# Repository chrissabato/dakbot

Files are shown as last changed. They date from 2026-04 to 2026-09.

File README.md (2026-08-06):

# dakbot

MicroPython firmware for the **Waveshare ESP32-S3-ETH** that reads live scoreboard data from a **Daktronics AllSport 5000** controller, or live timing data from a **Colorado System 7** swim-timing console, and serves it as JSON over Ethernet.

dakbot
dakbot

---

## How it works

dakbot supports two consoles, selected via the **Console Type** setting:

- **Daktronics AllSport 5000** — continuously broadcasts **RTD (Real Time Data)** packets over a serial port at 19200 baud. Each packet encodes a position and a text value that slots into a fixed-width string buffer. Field names and their byte positions are defined in `daksports.json` for each supported sport.
- **Colorado System 7** (swim timing) — outputs a continuous, unframed byte stream at 9600 baud driving a display matrix (module-address bytes select a channel/segment, data bytes carry 7-segment-style values). dakbot decodes this into a fixed lane-based schema (event/heat number, running clock, and place/time per lane) — there's no `daksports.json`-style variant selection for this console, since the schema doesn't vary by sport.

The ESP32 reads the selected console's serial stream over UART, updates the in-memory scoreboard state, and serves it as JSON on demand via a lightweight HTTP server. No SD card or file writes are needed — data lives in RAM and is always current.

Supported sports (Daktronics AllSport 5000): `baseball`, `basketball`, `volleyball`, `football`, `hockeylacrosse`

Supported swim console: `Colorado System 7` (fixed 6-lane schema)

---

## Hardware

- [Waveshare ESP32-S3-ETH](https://a.co/d/0aZ7pFHl)
- [MAX3232 level shifter](https://a.co/d/0iYqtyU6)
- AllSport 5000 RTD serial output → MAX3232 level shifter → GPIO16

> The AllSport 5000 outputs RS-232 voltage levels (±12 V). A level shifter such as the MAX3232 is required to convert to the 3.3 V logic the ESP32 expects. Connecting RS-232 directly will damage the board.

> **Colorado System 7:** this repo assumes the console's serial output is also RS-232 and requires the same MAX3232 level-shifting approach — but this is **unconfirmed**. There's no documented connector pinout or voltage spec for the Colorado System 7 in this repo (unlike the AllSport 5000's DB25 pinout below). Confirm the actual output voltage and connector pinout on your specific unit before wiring it to the ESP32; connecting the wrong voltage level directly will damage the board.

### Serial cable

The AllSport 5000 has a DB25 male RTD output. Wire it to a DB9 female connector for a standard MAX3232 module:

| AllSport 5000 DB25 Male | DB9 Female | Signal |
|---|---|---|
| Pin 7 | Pin 5 | GND |
| Pin 2 | Pin 3 | TX → RX |
| Pin 3 | Pin 2 | RX → TX (unused — receive only) |

### ESP Wiring

| MAX3232 | ESP32-S3-ETH |
|---|---|
| ACC | 3V3 |
| GND | GND |
| R1OUT | GPIO16 (UART RX) |
| R1IN | — |

GPIO17 is configured as UART TX but left unconnected — the AllSport link is receive-only.

### W5500 pins (fixed on-board, do not change)

| Signal | GPIO |
|---|---|
| SCLK | 13 |
| MOSI | 11 |
| MISO | 12 |
| CS | 14 |
| INT | 10 |
| RST | 9 |

---

## Installation

### Blank board setup

Requires Python 3. From inside the `dakbot` repo folder:

```bash
./setup.sh PORT
```

Replace `PORT` with your serial port:
- **Windows:** `COM3`, `COM4`, etc. — check Device Manager
- **Mac:** `/dev/cu.usbmodem*` or `/dev/cu.usbserial*`
- **Linux:** `/dev/ttyACM0` or `/dev/ttyUSB0`

The script installs `esptool`/`mpremote` if missing, downloads the latest stable MicroPython firmware for `ESP32_GENERIC_S3`, erases and flashes the board, verifies W5500 (Ethernet) support, and copies all project files. It will pause and prompt you to put the board in bootloader mode (hold **BOOT**, press and release **RESET**, release **BOOT**) and again to reset after flashing.

If W5500 verification fails, re-run with a manually downloaded `ESP32_GENERIC_S3-SPIRAM` build from [micropython.org/download/ESP32_GENERIC_S3](https://micropython.org/download/ESP32_GENERIC_S3/) by placing it in `/tmp/dakbot-firmware/` before running the script.

### Boot and verify

Press **RESET**. Connect to the REPL to see startup output:

```
Settings loaded from settings.json
Ethernet connected: ('192.168.x.x', '255.255.255.0', ...)
Sport: baseball | RTD buffer: 343 chars
HTTP server listening on port 80
Serial reader started
```

With Console Type set to Colorado System 7, the sport/RTD lines are replaced with:

```
Console: Colorado System 7
HTTP server listening on port 80
Colorado reader started
```

Open `http://<ip-shown-above>/settings` in a browser to confirm the UI is up.

---

## Configuration

User settings (sport, network, UART RX pin) are managed through the web UI at `/settings` and stored in `settings.json` on the device. Default values are defined in `settings.py`.

`config.py` contains only hardware pin constants fixed by the PCB — these should not need to change.

---

## Flashing updated code

After the initial install, copy individual changed files with `mpremote`:

```bash
mpremote connect PORT cp main.py :main.py
```

`settings.json` lives only on the device and is not overwritten by copying project files.

---

## Settings UI

Navigate to `http://<device-ip>/settings` to configure the device without reflashing.

| Setting | Notes |
|---|---|
| Console Type | Daktronics AllSport 5000 or Colorado System 7 — reboot required |
| Sport | Daktronics only; updates field mapping immediately on next reboot |
| DHCP / Static IP | Reboot required |
| HTTP Port | Reboot required |
| UART RX Pin | GPIO wired to the MAX3232 output — reboot required |
| MQTT Enable | Toggle MQTT publishing — reboot required |
| MQTT Broker | Hostname of the MQTT broker (TLS port 8883) |
| MQTT Topic | Topic to publish score data to (default: `dakbot/score`) |

Settings are persisted to `settings.json` on the device flash and survive reboots. Hardware pin constants (W5500 SPI lines, UART baud) stay in `config.py` and require reflashing to change.

---

## API

| Endpoint | Method | Description |
|---|---|---|
| `/` | GET | Live scoreboard JSON |
| `/data` | GET | Same (alias) |
| `/settings` | GET | Settings UI + device status dashboard (temp, RAM, uptime) |
| `/settings` | GET | Settings UI (HTML) |
| `/settings` | POST | Save settings to flash |
| `/reboot` | POST | Reboot device |
| `/update` | POST | OTA update from GitHub main branch |

All responses include `Access-Control-Allow-Origin: *`.

Example response (baseball):

```json
{
    "HomeTeamName": "HOME",
    "AwayTeamName": "GUEST",
    "HomeTeamScore": "9",
    "AwayTeamScore": "4",
    "Inning": "9",
    "InningText": "9TH",
    "InningDescription": "BOT of 9TH",
    "TB": "▼",
    "top": "",
    "bottom": "▼",
    "Ball": "0",
    "Strike": "0",
    "Out": "0",
    "Count": "0-0",
    "Outs": "⚪⚪⚪"
}
```

Example response (Colorado System 7):

```json
{
    "EventNumber": "12",
    "HeatNumber": "3",
    "Clock": "1:23",
    "Lane1Label": "1", "Lane1Place": "", "Lane1Time": "",
    "Lane2Label": "2", "Lane2Place": "1", "Lane2Time": "58.32",
    "Lane3Label": "3", "Lane3Place": "", "Lane3Time": "",
    "Lane4Label": "4", "Lane4Place": "", "Lane4Time": "",
    "Lane5Label": "5", "Lane5Place": "", "Lane5Time": "",
    "Lane6Label": "6", "Lane6Place": "", "Lane6Time": "",
    "console": "colorado"
}
```

---

## Files

| File | Purpose |
|---|---|
| `main.py` | Entry point — Ethernet init, async task runner |
| `daktronics.py` | Async AllSport 5000 RTD serial parser (machine.UART) |
| `colorado.py` | Async Colorado System 7 serial parser (machine.UART) |
| `webserver.py` | Minimal async HTTP server (uasyncio) |
| `mqtt_publisher.py` | Optional async MQTT publisher (TLS, port 8883) |
| `updater.py` | OTA updater — fetches project files from GitHub over HTTPS |
| `index.html` | Browser scoreboard — connects via MQTT WebSocket (WSS, port 8884); hosted at [chrissabato.github.io/dakbot](https://chrissabato.github.io/dakbot) |
| `config.py` | Hardware pin constants (PCB-fixed, do not change) |
| `settings.py` | Persistent user settings — loads/saves `settings.json` on flash |
| `daksports.json` | Field name → [position, length] mappings per sport |
| `setup.sh` | Full setup of a blank board — flash MicroPython + copy project files |
| `flash.sh` | Copy project files to an already-flashed board |

---

## MQTT / Public scoreboard

Enable MQTT in the `/settings` UI to push live scores to any MQTT broker. The browser client (`client.html`) connects to the same broker via WebSocket and displays the scoreboard in real time.

### Quick setup with HiveMQ Cloud (free tier)

1. Create a free cluster at [hivemq.com](https://www.hivemq.com/mqtt-cloud-broker/) — 10 connections, unlimited messages.
2. Create two credentials: one for the ESP32 (publish), one for the browser (subscribe-only).
3. In the Dakbot settings UI:
   - Enable MQTT
   - Broker: `xxxx.s1.eu.hivemq.cloud` (your cluster hostname)
   - Port: `8883` (TLS)
   - Fill in the ESP32 username/password
   - Topic: `dakbot/score` (or any string)
4. Install `umqtt.simple` on the device (one-time):
   ```bash
   mpremote connect PORT mip install umqtt.simple
   ```
5. Open `client.html` in any browser, enter the broker hostname, WSS port `8884`, and the browser credential.

The ESP32 publishes with `retain=True`, so late-joining browsers immediately receive the current score.

---

## 3D Printed Case

A 3MF print file for a case enclosing the ESP32-S3-ETH and MAX3232 module is included in [`resources/Dakbot Case.3mf`](https://github.com/chrissabato/dakbot/raw/main/resources/Dakbot%20Case.3mf). Open it in PrusaSlicer, Bambu Studio, or any slicer that supports the 3MF format.

---

## Credits

RTD serial parsing based on original work by [Alex Riviere](https://github.com/fimion) — [scoredata](https://github.com/chrisdeely/scoredata).

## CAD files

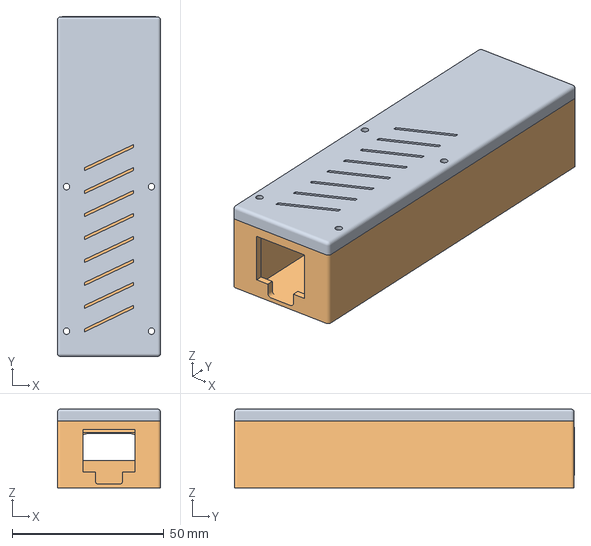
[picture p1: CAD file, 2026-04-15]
resources/Dakbot Case.3mf
34.0 x 112.1 x 26.0 mm

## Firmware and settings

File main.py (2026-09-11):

# =============================================================================
# main.py — ESP32-S3 Daktronics AllSport 5000 / Colorado System 7 → JSON web server
#
# Reads serial data from a Daktronics AllSport 5000 scoreboard controller or a
# Colorado System 7 swim-timing console (selected via the "console" setting),
# parses it into a dict, and serves the current state as JSON over Ethernet.
# A web UI at /settings allows configuration without reflashing.
#
# MicroPython build requirement:
#   The standard ESP32-S3 MicroPython binary does NOT include W5500 support.
#   You need a build compiled with: MICROPY_PY_NETWORK_WIZNET5K=5500
#   Build from source:
#     make BOARD=ESP32_GENERIC_S3 MICROPY_PY_NETWORK_WIZNET5K=5500
#   Verify: import network; print(hasattr(network, 'PHY_W5500'))  # must be True
#
# Flash the following files to the device root (/):
#   main.py, config.py, settings.py, daktronics.py, colorado.py, webserver.py,
#   daksports.json
# =============================================================================

import ujson
import uasyncio as asyncio
from machine import SPI, Pin

import config
import settings
import webserver
from daktronics import Daktronics


# =============================================================================
# Ethernet initialisation
# =============================================================================
def init_ethernet():
    """
    Bring up the W5500 using the ESP32-port network.LAN API.

    IMPORTANT: network.WIZNET5K is the RP2040/Pico API — it does not exist on
    ESP32. The correct API is network.LAN with phy_type=network.PHY_W5500.
    The INT pin is mandatory; the driver is interrupt-driven, not polling.

    For LAN8720 RMII boards (plain ESP32, not S3) swap to:
        nic = network.LAN(mdc=Pin(23), mdio=Pin(18),
                          phy_type=network.PHY_LAN8720, phy_addr=1)
    """
    import network
    import time

    spi = SPI(
        config.SPI_ID,
        baudrate=40_000_000,
        sck=Pin(config.SPI_SCK),    # GPIO13
        mosi=Pin(config.SPI_MOSI),  # GPIO11
        miso=Pin(config.SPI_MISO),  # GPIO12
    )

    nic = network.LAN(
        spi=spi,
        phy_type=network.PHY_W5500,
        phy_addr=0,                     # always 0 for SPI-based W5500
        cs=Pin(config.W5500_CS),        # GPIO14
        int=Pin(config.W5500_INT),      # GPIO10 — required by driver
        reset=Pin(config.W5500_RST),    # GPIO9
    )

    nic.active(True)

    try:
        settings.set_mac(nic.config('mac'))
    except Exception as e:
        print('WARNING: could not read Ethernet MAC:', e)

    s = settings.current
    if s.get('use_dhcp'):
        nic.ifconfig('dhcp')
        for _ in range(30):             # wait up to 15 s for DHCP lease
            if nic.isconnected():
                break
            time.sleep(0.5)
    else:
        nic.ifconfig((
            s.get('ip',      '192.168.1.100'),
            s.get('mask',    '255.255.255.0'),
            s.get('gateway', '192.168.1.1'),
            s.get('dns',     '8.8.8.8'),
        ))

    if nic.isconnected():
        print('Ethernet connected:', nic.ifconfig())
        webserver.device_ip = nic.ifconfig()[0]
    else:
        print('WARNING: Ethernet not connected — check wiring / settings')

    return nic


# =============================================================================
# Score processing
# =============================================================================

def build_score_dict(dak, sport_config):
    """Extract all fields from the RTD buffer into a flat dict."""
    data = {}
    for key in sport_config:
        data[key] = dak[key].strip()
    return data


# --- Sport-specific post-processors -----------------------------------------
# Each function receives the data dict and mutates it in place.
# Add a new entry here to support additional sports.

def _process_baseball(data):
    if 'HomeAtBat' in data:
        data['HomeAtBat'] = data['HomeAtBat'].replace('<', '>')

    ball, strike = data.get('Ball', ''), data.get('Strike', '')
    data['Count'] = '{}-{}'.format(ball, strike) if ball and strike else ''

    out_str = data.get('Out', '').strip()
    data['Outs'] = (
        '\u26ab\u26ab\u26ab' if out_str == '3' else   # ⚫⚫⚫
        '\u26ab\u26ab\u26aa' if out_str == '2' else   # ⚫⚫⚪
        '\u26ab\u26aa\u26aa' if out_str == '1' else   # ⚫⚪⚪
        '\u26aa\u26aa\u26aa' if out_str == '0' else   # ⚪⚪⚪
        ''
    )

    inning_state = data.get('InningDescription', '').lower()
    tb = (
        '\u25bc' if 'bot' in inning_state else
        '\u25b2' if 'top' in inning_state else
        ''
    )
    data['TB']     = tb
    data['top']    = '\u25b2' if tb == '\u25b2' else ''
    data['bottom'] = '\u25bc' if tb == '\u25bc' else ''

def _timeout_display(count_str):
    """2 -> '——'; blank/non-numeric -> ''."""
    try:
        n = int(count_str)
    except (ValueError, TypeError):
        return ''
    return '—' * n


def _process_football(data):
    down, togo = data.get('Down', ''), data.get('ToGo', '')
    data['DownAndDistance'] = '{} & {}'.format(down, togo) if down and togo else ''

    data['HomeTimeoutDisplay'] = _timeout_display(data.get('HomeTimeOutsLeft-Total', ''))
    data['AwayTimeoutDisplay'] = _timeout_display(data.get('AwayTimeOutsLeft-Total', ''))

    play_clock = data.get('PlayClockTime', '')
    try:
        under_10 = int(play_clock) < 10
    except (ValueError, TypeError):
        under_10 = False
    data['PlayClockTimeAlert'] = play_clock if under_10 else ''


_SPORT_PROCESSORS = {
    'baseball': _process_baseball,
    # 'basketball': _process_basketball,
    'football':   _process_football,
}


def apply_sport_processing(data, sport_name):
    processor = _SPORT_PROCESSORS.get(sport_name)
    if processor:
        processor(data)


# =============================================================================
# Async tasks
# =============================================================================
# Fields excluded from the "keep last known non-empty value" fallback below —
# these legitimately go blank as a normal state transition (not a serial
# glitch), so sticking them would make them permanently latch to their first
# non-blank value.
_STICKY_EXCLUDED = (
    'AwayAtBat', 'HomeAtBat',
    'DownAndDistance', 'HomeTimeoutDisplay', 'AwayTimeoutDisplay',
    'PlayClockTimeAlert',
)


async def serial_reader_task(dak, sport_config, sport_name, mqtt_enabled=False):
    """Read RTD packets continuously, yield between bytes for HTTP responsiveness."""
    print('Serial reader started')
    _mqtt_enabled = mqtt_enabled
    while True:
        try:
            await dak.update()
            new_data = build_score_dict(dak, sport_config)
            apply_sport_processing(new_data, sport_name)

            # Keep last known non-empty value for fields that report blank mid-packet
            for key, val in new_data.items():
                if key not in _STICKY_EXCLUDED:
                    if val == '' and key in webserver.score_data:
                        new_data[key] = webserver.score_data[key]

            new_data['sport'] = sport_name
            new_data['console'] = 'daktronics'
            webserver.score_data.update(new_data)

            # Signal MQTT publisher that fresh data is available
            if _mqtt_enabled:
                import mqtt_publisher
                mqtt_publisher.data_ready.set()

        except Exception as e:
            print('Serial reader error:', e)
            await asyncio.sleep_ms(500)


async def colorado_reader_task(cw, mqtt_enabled=False):
    """Read Colorado System 7 data continuously. update() only returns once
    a meaningful field has changed (see colorado.py)."""
    print('Colorado reader started')
    while True:
        try:
            await cw.update()
            new_data = cw.to_dict()
            new_data['console'] = 'colorado'
            webserver.score_data.update(new_data)

            if mqtt_enabled:
                import mqtt_publisher
                mqtt_publisher.data_ready.set()

        except Exception as e:
            print('Colorado reader error:', e)
            await asyncio.sleep_ms(500)


# =============================================================================
# Entry point
# =============================================================================
async def main():
    # 1. Ethernet (reads network settings from settings.current)
    init_ethernet()

    mqtt_enabled = bool(settings.current.get('mqtt_enabled'))
    console_type = settings.current.get('console', 'daktronics')

    # 2. Initialise the selected console's serial parser
    if console_type == 'colorado':
        from colorado import Colorado
        cw = Colorado(
            uart_id=config.UART_ID,
            rx_pin=settings.current['uart_rx'],
            tx_pin=settings.current.get('uart_tx', 17),
            baud=config.COLORADO_BAUD,
        )
        print('Console: Colorado System 7')

        # Seed score_data so the endpoint always returns valid JSON before first update
        webserver.score_data = cw.to_dict()
        webserver.score_data['console']     = 'colorado'
        webserver.score_data['device_name'] = settings.device_name()

        reader = colorado_reader_task(cw, mqtt_enabled)

    else:
        with open('daksports.json') as f:
            all_sports = ujson.load(f)

        sport_name   = settings.current['sport']
        sport_config = all_sports[sport_name]
        print('Sport:', sport_name, ' | RTD buffer:', sport_config['dakSize'][1], 'chars')

        dak = Daktronics(
            sport_config,
            uart_id=config.UART_ID,
            rx_pin=settings.current['uart_rx'],
            tx_pin=settings.current.get('uart_tx', 17),
            baud=config.UART_BAUD,
        )

        # Seed score_data so the endpoint always returns valid JSON before first packet
        webserver.score_data = {key: '' for key in sport_config}
        webserver.score_data['sport']       = sport_name
        webserver.score_data['console']     = 'daktronics'
        webserver.score_data['device_name'] = settings.device_name()

        reader = serial_reader_task(dak, sport_config, sport_name, mqtt_enabled)

    # 3. Run HTTP server and serial reader concurrently
    await webserver.start(port=settings.current.get('http_port', 80))

    tasks = [asyncio.create_task(reader)]

    # 4. Optionally start MQTT publisher
    if mqtt_enabled:
        import mqtt_publisher
        tasks.append(asyncio.create_task(
            mqtt_publisher.run(lambda: webserver.score_data)
        ))
        print('MQTT publisher task started')

    await asyncio.gather(*tasks)


asyncio.run(main())

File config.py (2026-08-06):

# =============================================================================
# config.py — Hardware-only constants for the Waveshare ESP32-S3-ETH
#
# These are fixed by the PCB and should not be changed.
# User-configurable settings (sport, IP, etc.) live in settings.py and are
# persisted to settings.json on the device flash.
#
# Pin assignments verified against the ESP32-S3-ETH schematic:
#   https://files.waveshare.com/wiki/ESP32-S3-ETH/ESP32-S3-ETH-Schematic.pdf
# =============================================================================

# --- UART hardware -----------------------------------------------------------
UART_ID       = 1
UART_BAUD     = 19200   # AllSport 5000 RTD fixed baud rate
COLORADO_BAUD = 9600    # Colorado System 7 fixed baud rate

# --- Ethernet (W5500 via SPI) ------------------------------------------------
# On ESP32-S3, W5500 uses network.LAN(phy_type=network.PHY_W5500, ...).
# network.WIZNET5K is the RP2040/Pico API and does not exist on ESP32.
# The INT pin is required — the driver is interrupt-driven, not polling.
SPI_ID    = 2    # SPI2 (HSPI) — SPI0/1 are reserved for internal flash
SPI_SCK   = 13   # W5500 SCLK
SPI_MOSI  = 11   # W5500 MOSI
SPI_MISO  = 12   # W5500 MISO
W5500_CS  = 14   # W5500 SCSn (chip select)
W5500_RST = 9    # W5500 RSTn (active-low reset)
W5500_INT = 10   # W5500 INTn (interrupt — required by network.LAN driver)

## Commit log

2026-04-06 Initial commit: Daktronics AllSport 5000 scoreboard reader
    Original Python/pyserial implementation (daktronics.py, scorebug.py)
    plus ESP32-S3 MicroPython port targeting the Waveshare ESP32-S3-ETH board.
    The ESP32 port reads RTD serial data over UART, parses it using the
    same positional field mapping from daksports.json, and serves live
    scoreboard JSON over Ethernet via a lightweight async HTTP server.
2026-04-06 Add README
    Covers both the Python/PC implementation and the ESP32-S3 MicroPython
    port: hardware wiring, level shifter requirement, firmware build notes,
    flashing instructions, and HTTP API reference.
2026-04-06 Restructure as ESP32-S3 MicroPython project
    Remove legacy Python/pyserial implementation. Promote esp32/ contents
    to repo root. Update README to reflect ESP32-only scope.
2026-04-06 Add web UI for settings management
    - settings.py: persistent user settings (sport, network, UART RX pin)
    loaded from settings.json on flash; falls back to defaults if missing
    - webserver.py: add GET/POST /settings (HTML form), POST /reboot;
    URL-decode helper and form parser for handling POST bodies
    - config.py: strip to hardware-only pin constants; all user config
    moved to settings.py
    - main.py: read sport, network, and UART RX from settings.current
    - .gitignore: exclude settings.json (device-specific, generated at runtime)
    - README: update configuration section and API table
    [config.py, main.py, settings.py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]
2026-04-08 Add flash.sh script for copying files to device
    Usage: ./flash.sh [port] (defaults to /dev/ttyACM0)
2026-04-08 Fix flash.sh to copy files individually
    Chained mpremote + syntax was unreliable. Copy each file in a
    separate mpremote call with error checking.
2026-04-09 Add MQTT publishing and browser scoreboard client
    - settings.py: add mqtt_enabled, broker, port, user, password, topic defaults
    - mqtt_publisher.py: async TLS MQTT publisher; publishes on change, pings every 30s, reconnects on failure
    - webserver.py: add MQTT section to settings form and POST handler
    - main.py: conditionally start MQTT task via asyncio.gather
    - client.html: browser scoreboard using MQTT.js over WSS; config panel for broker credentials
    - flash.sh: include mqtt_publisher.py in copy list
    - README: document MQTT setup with HiveMQ Cloud
    [main.py, mqtt_publisher.py, settings.py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]
2026-04-10 Add sport-specific scoreboard layouts to browser client
    Each sport now has a dedicated renderer showing only relevant fields:
    - Baseball: inning description, count/outs, H/E/LOB table
    - Basketball: game/period + clock, fouls, bonus, shot clock
    - Football: quarter + clock, down & distance, ball on, play clock
    - Volleyball: set number, sets won, serve indicator
    - Hockey/Lacrosse: period + clock, shots on goal, saves
    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
2026-04-10 Replace MQTT polling with event-driven publish
    mqtt_publisher now waits on an asyncio.Event (data_ready) instead of
    sleeping on a timer. serial_reader_task sets the event on every RTD
    packet, triggering an immediate publish. Eliminates up to 1s polling
    delay — latency is now just the broker round-trip (~200-300ms).
    [main.py, mqtt_publisher.py]
2026-04-10 Fix MicroPython API errors in mqtt_publisher
    asyncio.ticks_ms/ticks_diff/wait_for_ms don't exist in uasyncio.
    Use utime.ticks_ms/ticks_diff and asyncio.wait_for (seconds) instead.
    These crashes were preventing the HTTP server from responding.
    [mqtt_publisher.py]
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2026-04-11 Add OTA firmware update from GitHub via settings UI
    - updater.py: fetches each project file from raw.githubusercontent.com
    over HTTPS using raw sockets + TLS (no extra packages needed).
    Writes to a .tmp file then renames for safety. settings.json is never touched.
    - webserver.py: POST /update runs the updater and shows a results page
    with per-file status; includes a Reboot button to apply.
    Settings page has an 'Update from GitHub' button with a loading state.
    - flash.sh: include updater.py in initial flash
    - README: document /update endpoint and updater.py file
    [updater.py, webserver.py]
2026-04-11 Add device status dashboard to settings page
    Renders IP, sport, MCU temp, RAM, and uptime directly in the settings
    page response — no separate endpoint or JS polling needed.
    Removed /health and /status endpoints.
2026-04-11 Fix OTA update hanging — send response before downloading files
    The update handler now responds immediately with a progress page, then
    starts the download in a background asyncio task. Previously the
    synchronous HTTPS downloads blocked the event loop before the HTTP
    response could be flushed, leaving the browser spinning forever.
    [webserver.py]
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2026-04-11 Fix TypeError crash in settings page — remove double unary +
    [webserver.py]
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2026-04-14 Switch browser MQTT client to self-hosted Mosquitto broker
    Default host/port/user now points to stats.chrissabato.com via Apache
    WSS proxy on port 443. Update config panel note accordingly.
2026-04-15 Add 3D printed case file and document in README
    [Dakbot Case.3mf]
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2026-04-16 Remove index.json, ignore monitor.py, fix TB field for neutral inning state
    TB now returns empty string when InningDescription is neither top nor bottom.
    [main.py]
2026-07-30 Send Cache-Control: no-store on HTTP responses
    Prevents browsers from serving a stale cached JSON/settings response
    instead of hitting the device for fresh data.
    [webserver.py]
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2026-07-30 Support multiple MQTT devices and add a server-side devices dashboard
    Give each device a unique MQTT client ID and topic (MAC-scoped) so
    multiple dakbot units can publish to the same broker without kicking
    each other off. Add a PHP/JS server component that polls the broker
    and shows all connected devices, with links to each device's raw JSON
    and a detailed live monitor view.
    [mqtt_publisher.py, settings.py, webserver.py]
2026-07-30 Add single-script blank-board setup and validate MQTT broker hostname input
    setup.sh flashes MicroPython, verifies W5500 support, and copies project
    files in one step, replacing the multi-step manual install in the README.
    webserver.py now strips a pasted URL scheme/path from the MQTT broker
    field so it saves as a bare hostname, since the raw socket connect needs
    one and a pasted URL was silently breaking MQTT.
    [webserver.py]
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2026-09-07 Cache MQTT device state for api.php and clean up vMix-hostile field names
    api.php shelled out to mosquitto_sub with a 3s timeout on every request,
    blocking each page load. A persistent daemon now keeps one subscription
    open and writes device state to a cache file that api.php just reads.
    Also strip [], (), and leading-digit characters from basketball,
    football, and hockeylacrosse field names in daksports.json — vMix's
    data-source binding can't parse keys containing them, matching the
    clean naming baseball/volleyball already used.
2026-09-07 Log OTA update results to a file for debugging
    daksports.json isn't landing on the device after /update even though
    the version check reports up to date, and _do_update() was discarding
    updater.update_all()'s per-file results, so there was no way to see
    which file's fetch actually failed. Adds a temporary GET /update-log
    endpoint to inspect the last run's results.
    [webserver.py]
2026-09-07 Fix OTA updater hanging indefinitely on some fetches
    updater.py read the HTTP response body in a loop until the socket
    returned no data, relying on the server closing the connection.
    raw.githubusercontent.com (Fastly) doesn't always do that for an
    HTTP/1.0 request, so the read loop could block forever with no
    timeout — confirmed live via serial console, where update_all()
    hung on a device that otherwise responded fine over HTTP the whole
    time (it runs synchronously in a background task, so a hang there
    never touched the running webserver).
    Now reads exactly Content-Length bytes instead of waiting for close,
    and sets a socket timeout as a backstop.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
    [updater.py]
2026-09-07 Cache-bust OTA file fetches to avoid stale CDN edges
    raw.githubusercontent.com's CDN doesn't invalidate every edge
    instantly after a push, so the device could fetch a stale cached
    copy of a file for a while after bumping VERSION (observed directly:
    version.py briefly served 95 stale bytes for a since-updated 96-byte
    file). Adding a per-request cache-busting query string forces each
    fetch to bypass any stale cached response.
    [updater.py]
2026-09-07 Fix OTA MemoryError on larger files by streaming to disk
    update-log (added this session for exactly this) finally caught the
    real failure: webserver.py and daksports.json were failing with
    "memory allocation failed" on the ESP32. _fetch() accumulated the
    whole HTTP response into one growing bytes object, reallocating a
    bigger buffer on every 4KB chunk — fine for small files, but on the
    device's fragmented heap (especially with the async webserver,
    serial reader, and MQTT publisher all live) it couldn't find a
    contiguous block for anything much above ~15KB. This is why
    daksports.json specifically kept silently failing to update all
    session, even though smaller files updated fine.
    _fetch_to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
    [updater.py]
2026-09-07 Remove temporary OTA debug logging endpoint
    update_log.json / GET /update-log were added mid-debugging to find
    the update_all() MemoryError; no longer needed now that it's fixed.
    [webserver.py]
2026-09-07 Add timeout dash display and play-clock alert for football
    HomeTimeoutDisplay/AwayTimeoutDisplay render TimeOutsLeft-Total as a
    dash count (2 -> "——"). PlayClockTimeAlert mirrors PlayClockTime when
    under 10 seconds, empty otherwise. Both guard against blank/non-numeric
    input rather than raising, since PlayClockTime is blank for most of a
    dead-ball period and an uncaught exception here would have silently
    stalled the whole score dict update, not just this field.
    [main.py]
2026-09-07 Exclude derived football fields from sticky-blank fallback
    serial_reader_task keeps the last known non-empty value for any field
    that reads blank, to smooth over transient serial glitches. It was
    also catching derived fields (DownAndDistance, HomeTimeoutDisplay,
    AwayTimeoutDisplay, PlayClockTimeAlert) that legitimately go blank as
    a normal state change — e.g. PlayClockTimeAlert clearing once the
    play clock resets above 9 — so once set, they could never go blank
    again for the rest of the game.
    [main.py]
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2026-09-16 Make OTA update atomic and add a manual Force Reinstall option
    update_all() previously committed each downloaded file to flash as soon as
    it fetched, including version.py near the end of the list. A failure
    partway through (e.g. a MemoryError on a larger file like webserver.py)
    could leave a broken mix of old and new files while version.py still
    advanced, so the settings page would report "up to date" even though the
    installed code was stale and inconsistent.
    Now every file downloads to a .tmp sibling first, with retries and a
    gc.collect() per attempt, and the whole set is only renamed into place if
    every file succeeded — otherwise the previous, fully-working fileset is
    left untouched and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
    [updater.py, webserver.py]
2026-09-16 Fix Colorado event-loop starvation and settings-page reboot messaging
    colorado.py's _read_byte() only yielded to the scheduler when the UART had
    no byte ready. Colorado System 7 streams its full display matrix
    continuously even when nothing visible has changed, so bytes are usually
    already available — meaning update()'s loop (which can run for up to a
    full second between exposed-field changes) never actually suspended during
    that stretch, starving every other task. This blocked the HTTP server from
    responding promptly and could stall the MQTT publisher long enough to miss
    its keepalive and drop the broker connection, both matching reports of a
    sluggish JSON endpoint and a Colorado device n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
    [colorado.py, webserver.py]
2026-09-16 Add device staleness/expiry and Colorado rendering to the dashboard
    mqtt-cache-daemon.php now subscribes with -R so a broker reconnect doesn't
    replay every device's last retained message and make a dead device look
    freshly seen, seeds its in-memory map from the existing cache file so
    lastSeen survives a daemon restart, records lastSeen per message, and prunes
    devices that haven't published in DEVICE_EXPIRE_SECONDS. api.php uses that
    to drop long-silent devices from its response and flag merely-old ones as
    'stale' for the dashboard to grey out. New DEVICE_STALE_SECONDS/
    DEVICE_EXPIRE_SECONDS constants live in config.php.example.
    index.html and monitor/index.html previously rendered every dev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
2026-09-16 Stop the Device Name field from freezing a stale MAC into settings.json
    The Identity form's device_name input was pre-filled with the *effective*
    name (settings.device_name(), already falling back to the MAC-derived
    default) rather than the raw stored override. Since that's a normal text
    input, the browser submits whatever's showing on every save regardless of
    whether the user edited it — so the very first settings save on a device
    silently baked the then-current default into settings.json forever. From
    then on device_name() returns that frozen snapshot instead of recomputing
    from the live MAC, while mqtt_topic (built correctly, using the raw stored
    value with the default only as a placeho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
    [webserver.py]
2026-09-16 Fix transient garbled clock values from unvalidated nibble decode
    colorado.py's data-byte handler XORs each 4-bit nibble with 0x0F to decode
    a digit. For nibble values 6-15 that correctly yields 0-9, but for 1-5 it
    yields 10-14 — not a valid digit — and nothing checked for that before
    storing it in the display matrix. The running-clock and lane-time builders
    str() each segment directly, so a 10-14 value silently became a
    two-character substring ("12" instead of a single digit) for that one
    frame, showing up as the clock transiently flashing to a garbled,
    roughly-double-length value before the next valid nibble corrected it.
    Now any decoded value outside 0-9 is treated as blank, so a str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
    [colorado.py]
2026-09-16 Gate event/heat number changes on the last segment, like clock/lane times
    The event/heat block (Channel 12) compared the decoded event/heat number
    against the committed value on every single byte touching that channel,
    with no gate on the field actually being fully updated for this scan pass
    — unlike the running clock and lane-time blocks, which already wait for
    their field's last segment (sec01 / ten01) before treating a value as real.
    A mid-scan torn read (only one of the two event or heat digits updated so
    far, or one blanked by the invalid-nibble guard added for the clock-digit
    glitch) reads as a mismatch against the committed number, which called
    _reset_time() and wiped every lane an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
    [colorado.py]
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2026-09-16 Make update_all() never raise, so a commit failure can't silently kill OTA
    The final rename-into-place loop in update_all() had no exception handling
    at all. If a single rename ever failed there — rare, since renames are
    metadata-only, but not impossible — the exception propagated straight out
    of update_all() and out of _do_update(), which is a bare
    asyncio.create_task() with nothing to catch it. That silently kills the
    background task before it reaches either machine.reset() or the
    error-banner code, so the update just does nothing visible: no reboot, no
    version bump, no error — exactly what was reported ("Version 23 available
    (installed: 22)" with no error shown after clicking update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
    [updater.py, webserver.py]
2026-09-16 Stop wiping the running clock on every event/heat change
    _reset_time() rebuilt every row 0..lanes from scratch, but index 0 isn't a
    lane — to_dict() reads self._time[0][2] as the main Clock. Channel 12's
    event/heat-change handler calls _reset_time() on every heat transition (by
    design, to clear stale per-lane data for the new heat), which also blanked
    the clock every time, even though it runs independently of which heat is
    showing. That's a routine, recurring event during a meet, so the served
    Clock kept going blank — rendered as '—' on the dashboard/monitor pages —
    which is likely most of what's still being seen as "flashes" after the
    earlier decode-level fixes.
    Index 0 is now pres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
    [colorado.py]
2026-09-16 Exclude channel 0 from the Lane Times block, not just lane-blanking
    Channel 0 (the main clock) was still being processed by the "Lane Times"
    block despite the earlier fix that excluded it from the lane-blanking
    block above. This block's own all-blank check has no gate at all: it
    directly clears self._time[ln][2] to '' whenever a lane's six segments
    (2-7) all read blank, with no equivalent of the sec01 != ' ' gate that
    protects the Running Time block from the same situation.
    Since the "Blank out lane info" block wipes channel 0's segments 1-7 on
    every address byte 191/254/255 — routine, continuous, and unrelated to
    event/heat changes — segments 2-7 read all-blank immediately afterward,
    s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
    [colorado.py]
2026-09-16 Debounce event/heat number commits against one-off decode glitches
    Reported: HeatNumber briefly flashed from "1" to "44" and back, with no
    actual heat change on the console. Unlike the earlier out-of-range nibble
    guard (which catches impossible values), a misaligned or corrupted byte
    can decode to a plausible-but-wrong digit that passes every existing
    check, gets treated as a real change, and — worse — triggers
    _reset_time(), cascading into the broader lane/clock disruption already
    being fixed.
    Channel 12 now stages a newly-decoded (event, heat) pair and only commits
    it once the identical value is read on a second, consecutive qualifying
    pass. A genuine change naturally repeats on the v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
    [colorado.py]
2026-09-16 Gate the published Clock like the proven Raspberry Pi reference did
    Compared this module against the original Raspberry Pi/pyserial reference
    script (gist: 558f3603b629305b0ae564762c4420db) that ran this exact
    protocol without issue. The core decode logic turns out to be identical
    between the two — unvalidated nibble XOR, an ungated Channel 12 compare,
    a reset that touches the clock's slot, channel 0 included in the lane
    range — none of that is a porting bug. The actual difference is
    architectural: the reference never let any of that internal state reach
    its output directly. Its Running Time section only ever wrote the clock
    to the file that drove the display when the freshly-computed va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
    [colorado.py]
2026-09-16 Debounce event/heat across scan passes, not just consecutive bytes
    Reported: the "1 -> 44 -> 1" heat glitch still occurred after the previous
    debounce fix. The flaw: that fix compared each reading against whatever
    was read on the immediately preceding byte touching Channel 12 — but a
    single address byte (166/167/230/231) is typically followed by several
    data bytes (one per segment) within the same scan pass. A corruption burst
    spanning more than one of those bytes could produce the same wrong value
    on two consecutive per-byte evaluations that both belong to the *same*
    pass, trivially satisfying the old check without ever representing two
    independent readings.
    Now _ch12_pass increments on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
    [colorado.py]
2026-09-16 Require a lane to be seen blank before trusting new data after a heat reset
    Reported: right after advancing to a new heat, before the clock restarts,
    lane data briefly flashes "44", "44.44", or "44:44.44". The consistency of
    that value (always 4, in every digit position) points to something
    specific about the gap right after a heat reset — before the console is
    actually ready with real per-lane data — rather than random line noise;
    the existing lane-time gate (ten01 != ' ') only checks that *some* value
    is present, not that it's genuinely post-transition real data.
    Each lane now tracks whether it's been observed fully blank since the
    last heat reset (self._lane_seen_blank), cleared on e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
    [colorado.py]
2026-09-16 Cross-pass confirm lane times too, not just seen-blank
    Reported: still seeing "44:44.44" on a lane (this time Lane6Time, with
    Event/Heat reading correctly as 2/4) despite the previous seen-blank gate.
    The pattern — always exactly one field affected at the moment of a heat
    transition, always digit 4 throughout — points to a timing race on the
    console's own side: its internal state has already moved on, but whichever
    channel the continuous scan happens to be mid-write on at that instant can
    briefly reflect stale/in-flux register state. A transitional blank frame
    can be part of that same in-flux window, so "wait for one observed blank"
    isn't sufficient by itself — it can be satisfied righ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
    [colorado.py]
2026-09-17 Fix Colorado byte-loss under real scheduling load, plus torn-read gaps
    The real root cause of persistent garbage digits (almost always "4") in
    the Colorado feed: update() read the UART one byte at a time, yielding
    to the scheduler via asyncio.sleep_ms(0) after every single byte. At
    9600 baud (~960 bytes/sec), that yield-and-reschedule overhead is
    itself slower than bytes arrive once other tasks (HTTP server, MQTT
    publisher) exist to compete for CPU time -- confirmed live by watching
    the UART's receive buffer climb to its full 4096-byte cap and stay
    pinned there. Once it overflowed, incoming bytes got corrupted/
    misaligned. A dedicated single-purpose reference script (colorado-og.py,
    added he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
    [capture_dakbot.py, capture_usb_serial.py, colorado-og.py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]
2026-09-17 Track Label/Place independently of Time; fix JSON key sorting on device
    Lane Label and Place are sent by the console on every refresh cycle
    regardless of whether that lane currently has a time, but their
    confirmation was gated on Time's own trigger (ten01 present) -- both
    in this module's own prior fix and in the trusted colorado-og.py
    reference logic. A lane with no time yet, the normal state before a
    race finishes (or any lane that's simply off), never had its
    Label/Place read at all, leaving them frozen at whatever
    _reset_time() initialized them to -- confirmed live as Lane1Label
    staying stuck at "1" instead of reflecting the console (e.g. going
    blank when a lane is disabled). Label + Pla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
    [colorado.py, mqtt_publisher.py, webserver.py]
2026-09-17 Stop requiring sec10 to be present, which froze Clock on every reset
    Clock and Lane Times both required sec10 (tens-of-seconds) to be
    non-blank before trusting a reading -- a defensive measure added
    earlier for a torn-read bug whose real cause (UART byte loss under
    scheduling load) is now fixed properly. That requirement was based on
    an assumption that turned out to be wrong: confirmed live, the console
    legitimately blanks tens-of-seconds under 10 real seconds, exactly the
    way it already blanks tens-of-minutes under 10 minutes. A freshly
    reset clock reads as sec10=' ', sec01='0' on every single cycle, so
    the requirement permanently blocked Clock from ever publishing a
    sub-10-second reading -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
    [colorado.py]
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
